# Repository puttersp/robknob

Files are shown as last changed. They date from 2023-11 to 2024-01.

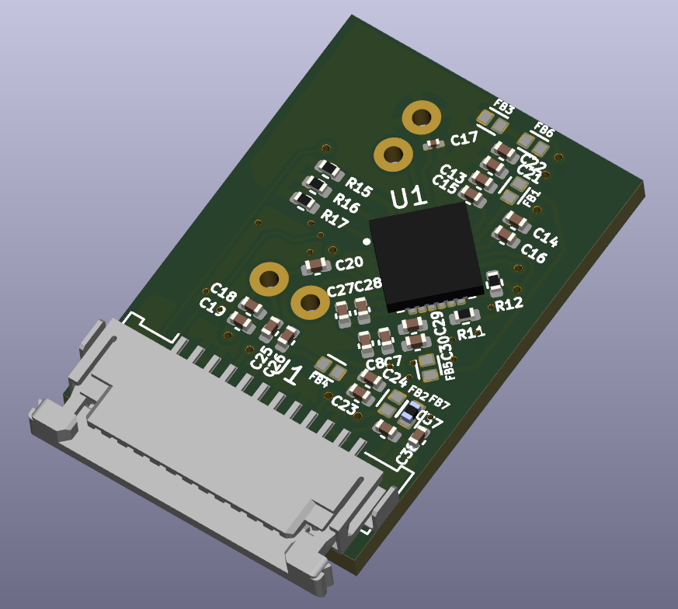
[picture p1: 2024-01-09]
electronics/lidar_pcb.png

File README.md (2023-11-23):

# robknob
## Robknob is a smartknob for robotics.
### FEATURES
- Smartknob with Haptic feedback
    - 3 Hapfic feedback modes
        - Fine steps with low detents
        - Rough steps with medium detents
        - Fine steps with medium detents and Bounded with high detents
    - Press for mode change
        - 3 steps press with strain gauges
            - Different colors displayed by LED Strips for different steps
        - LiDAR Mode for Robot Navigation
        - PID Tuning Mode
        - IMU Display
    - 240x240 Round LCD Display
- LiDAR with 4000Hz Sampling Rate 5M Range
- 6-DOF IMU for Robot Navigation
- ROS2 Compatible

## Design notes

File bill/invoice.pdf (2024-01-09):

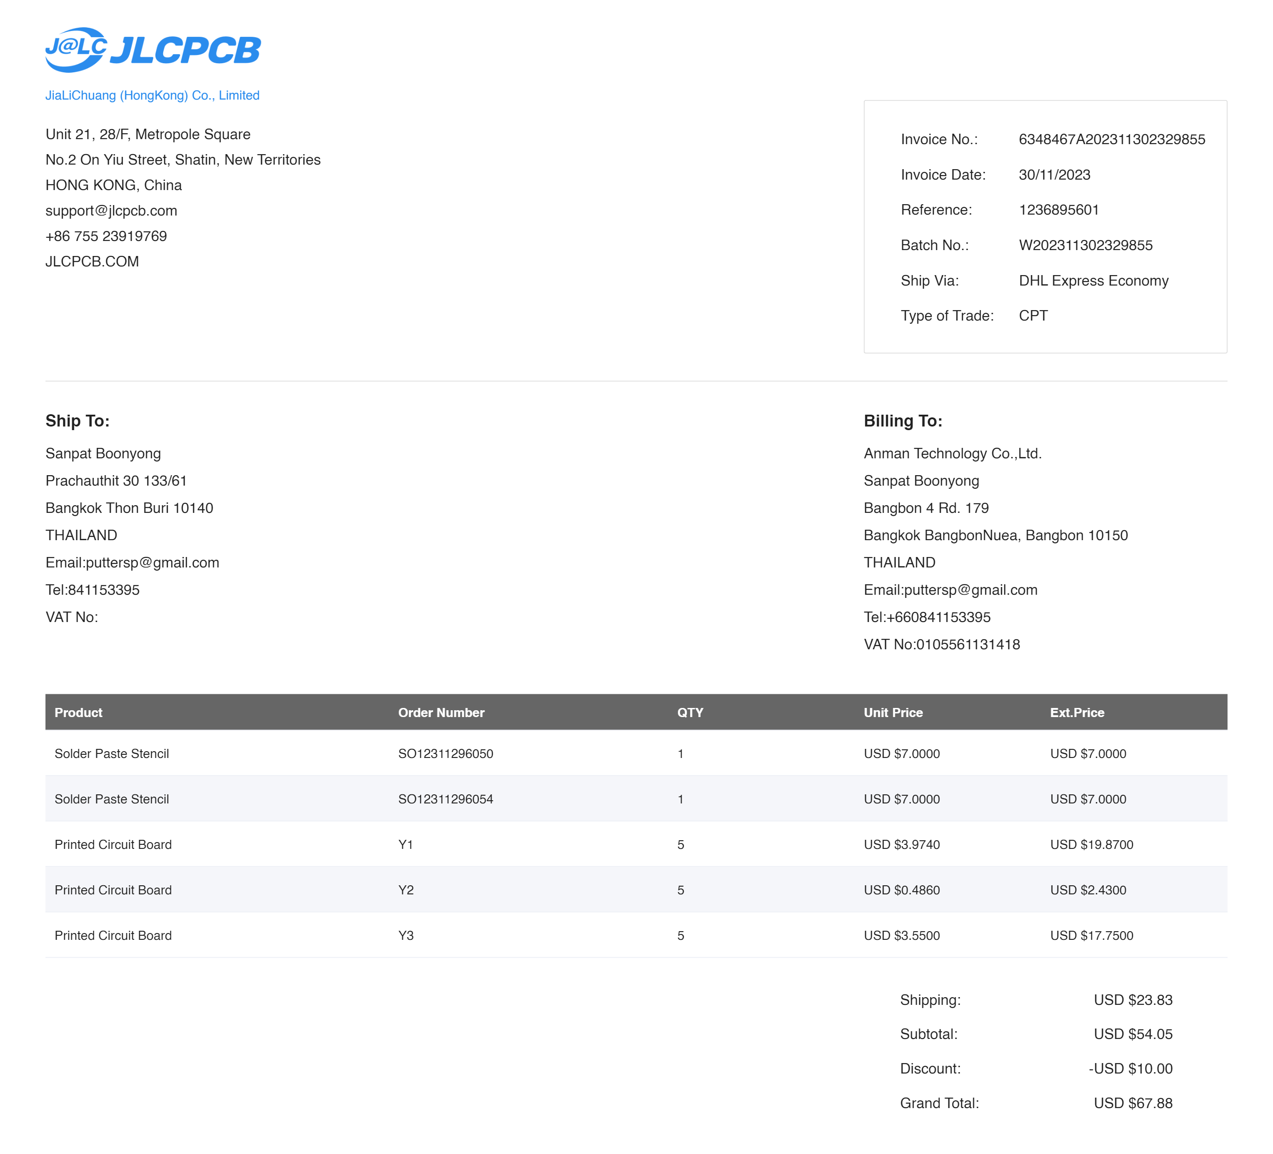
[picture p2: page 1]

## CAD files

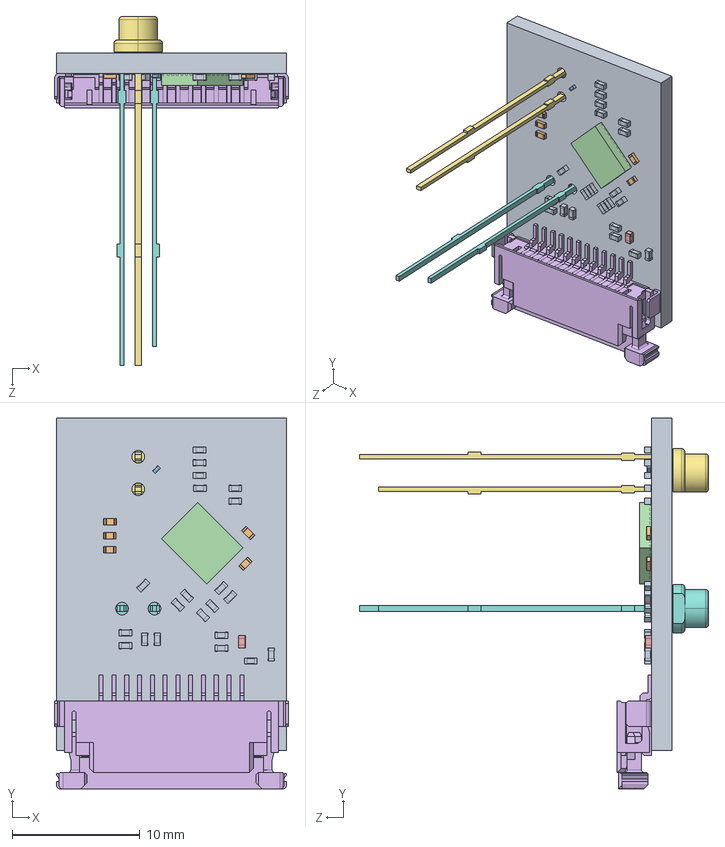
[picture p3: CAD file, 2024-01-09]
cad/Lidar.SLDASM
18.3 x 29.0 x 27.3 mm
SOLID.step x 21
SOLID-0.step x 5
SOLID-1.step
COMPOUND.step
COMPOUND-2.step
COMPOUND-3.step
COMPOUND-4.step
COMPOUND-5.step
lidar PCB.step

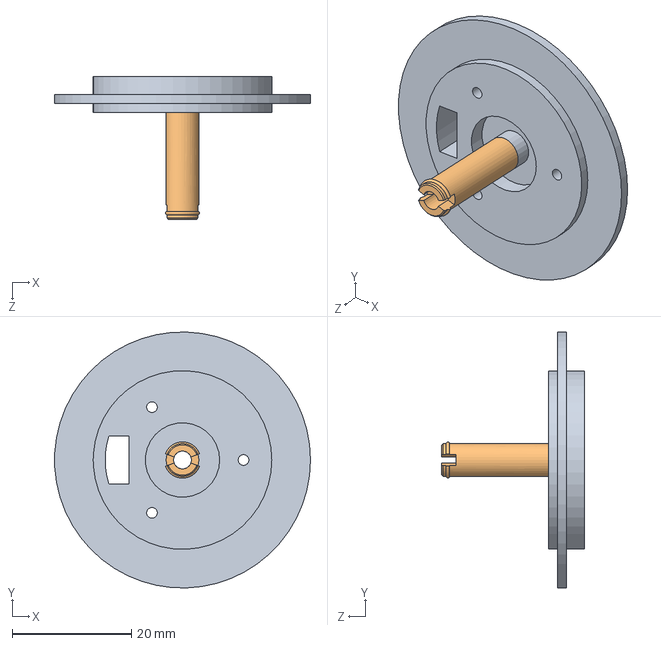
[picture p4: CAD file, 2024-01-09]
cad/MountBaseNew.SLDASM
43.0 x 43.0 x 24.0 mm
MountBaseBasePart
MountBaseLongPart

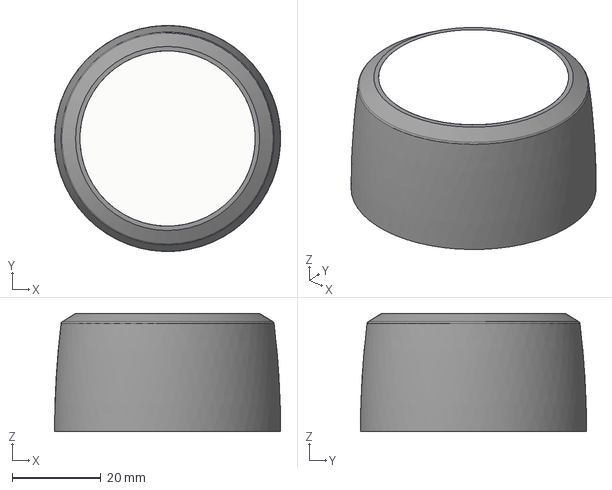
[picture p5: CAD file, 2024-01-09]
cad/KnobAssembly.step
51.0 x 51.0 x 26.7 mm

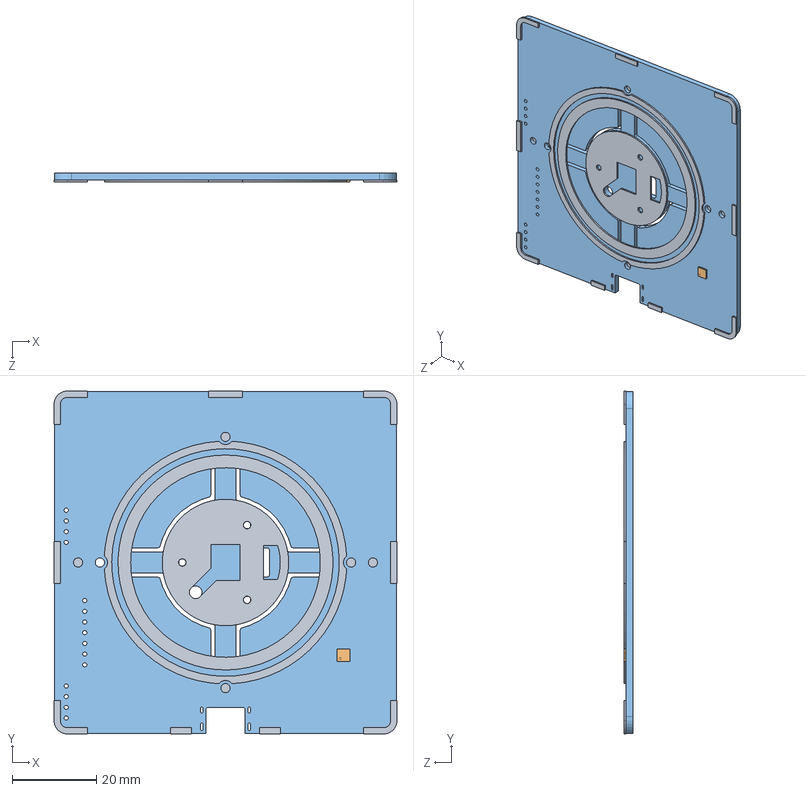
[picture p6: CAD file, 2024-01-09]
cad/Base_bare.SLDASM
81.4 x 81.4 x 2.22 mm
COMPOUND-3.step
SOLID-5.step
view_base PCB.step

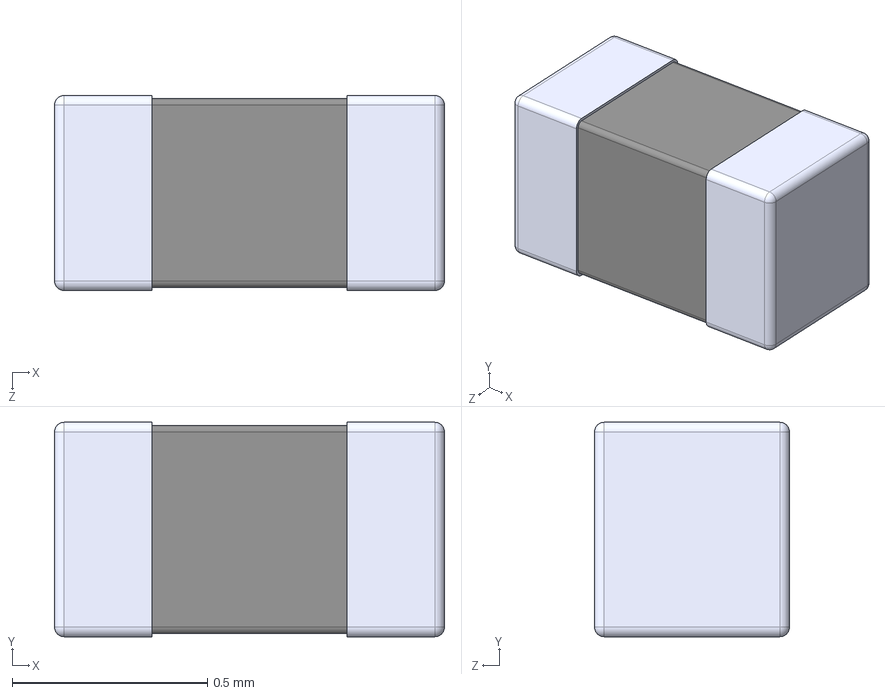
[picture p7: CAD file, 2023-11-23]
Kicad/BEADC1005X50N/NFZ15SR262SN10D.STEP
1.00 x 0.55 x 0.5 mm

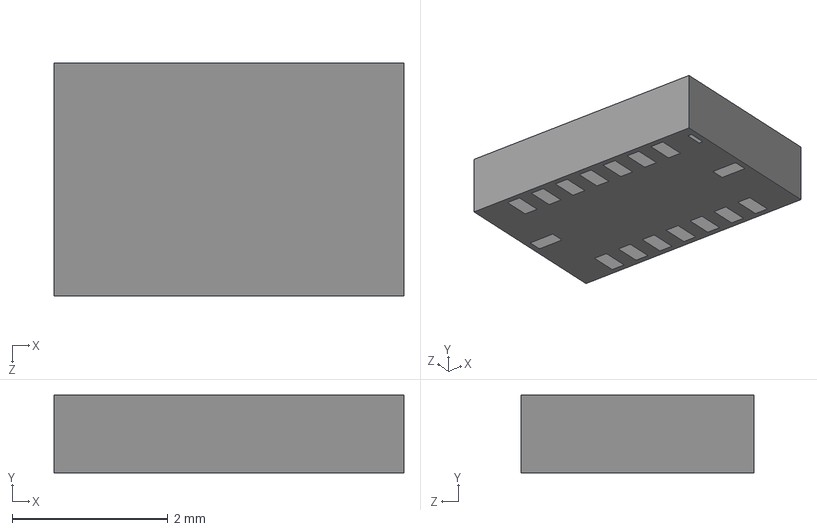
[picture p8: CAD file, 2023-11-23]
Kicad/BMI088/BMI088.step
4.50 x 1.00 x 3.00 mm

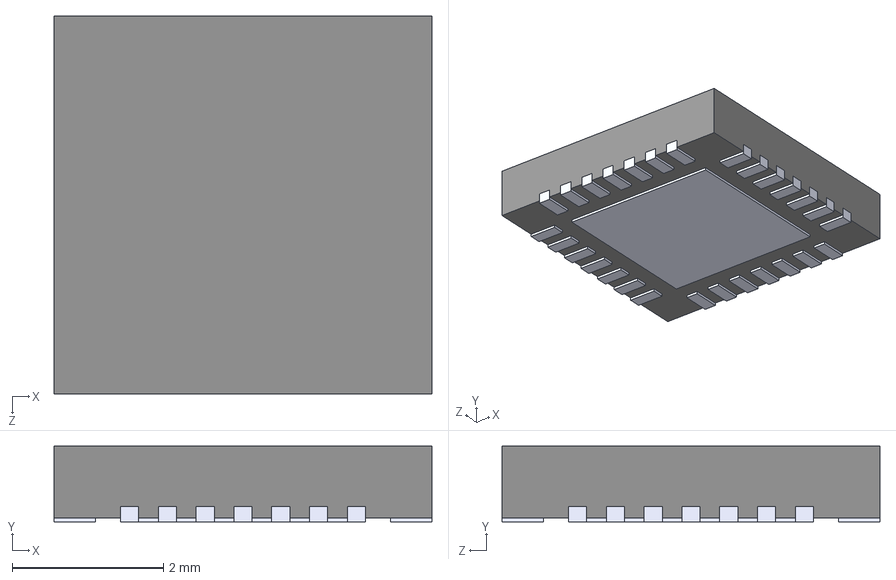
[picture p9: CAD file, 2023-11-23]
Kicad/OPT3101RHFR/CC2520RHDRG4.STEP
5.00 x 1 x 5.00 mm

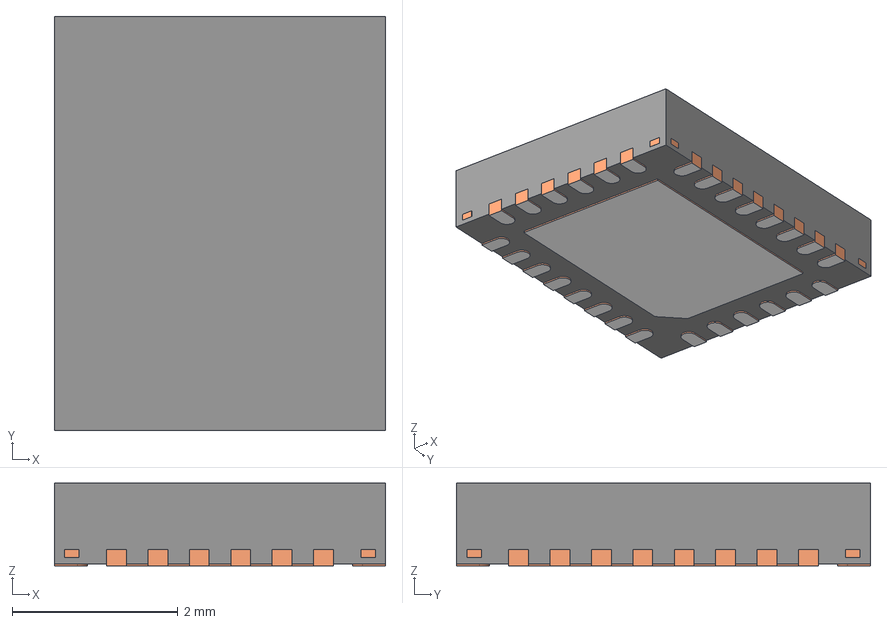
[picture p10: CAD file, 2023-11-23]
Kicad/OPT3101RHFR/OPT3101RHFR/3D/OPT3101RHFR.stp
4.00 x 5.00 x 1.00 mm
BODY-QFN
FRAME-RHF0028A
PIN1-ID

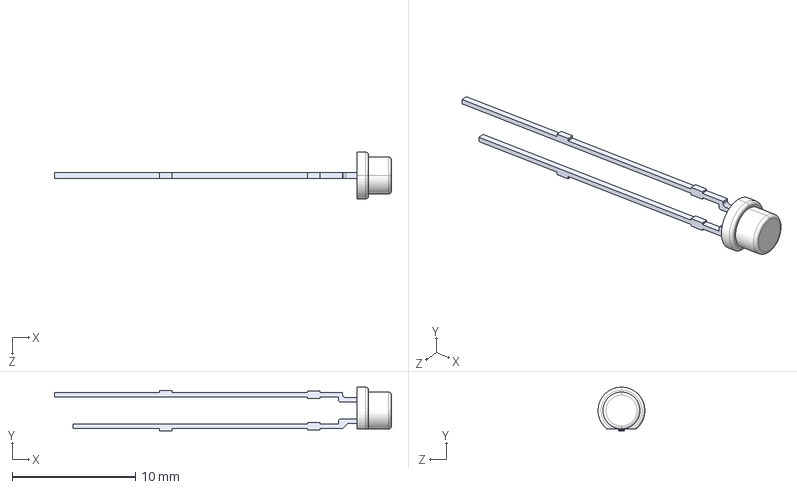
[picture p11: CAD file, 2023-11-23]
Kicad/SFH213FA/SFH_213_FA.step
27.3 x 3.55 x 3.80 mm

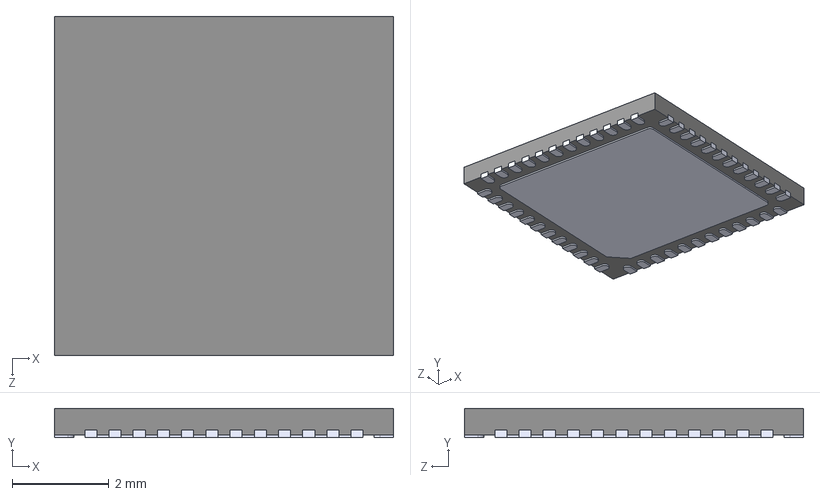
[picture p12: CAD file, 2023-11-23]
Kicad/STM32F411CEU6/STM32F411CEU6.step
7.00 x 0.6 x 7.00 mm

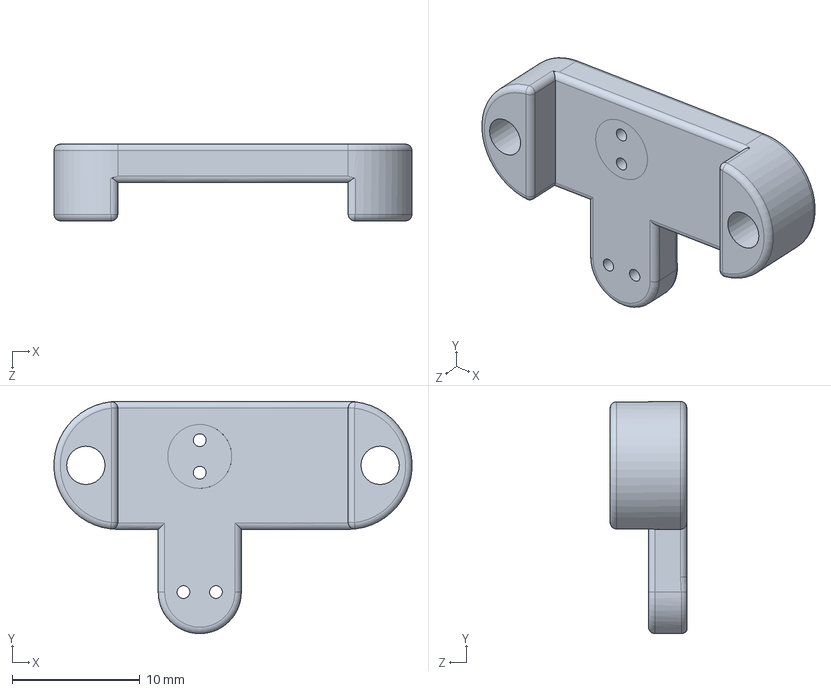
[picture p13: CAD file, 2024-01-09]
cad/lidar_mount2.SLDPRT
28.0 x 18.1 x 6.00 mm

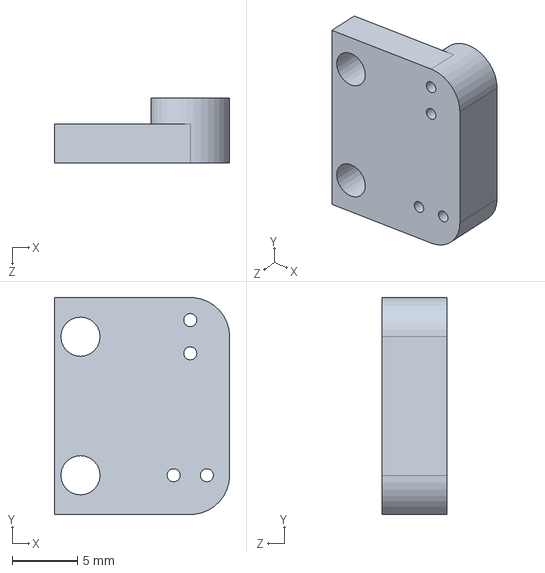
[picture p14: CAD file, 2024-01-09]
cad/lidar_mount3.SLDPRT
13.4 x 16.6 x 5.00 mm

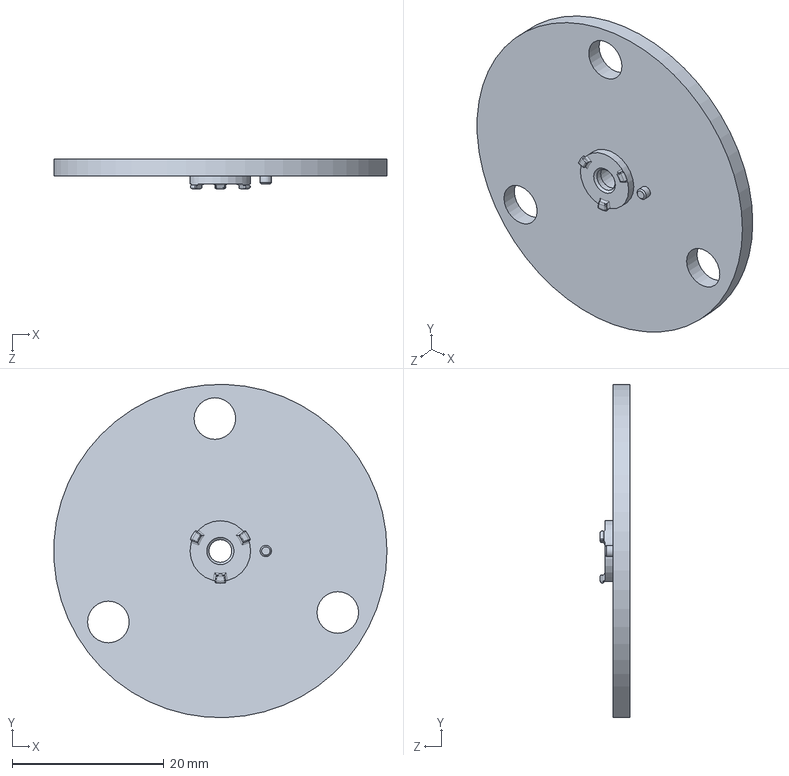
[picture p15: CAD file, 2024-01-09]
cad/ScreenPlatformNew.SLDPRT
44.0 x 44.0 x 3.90 mm

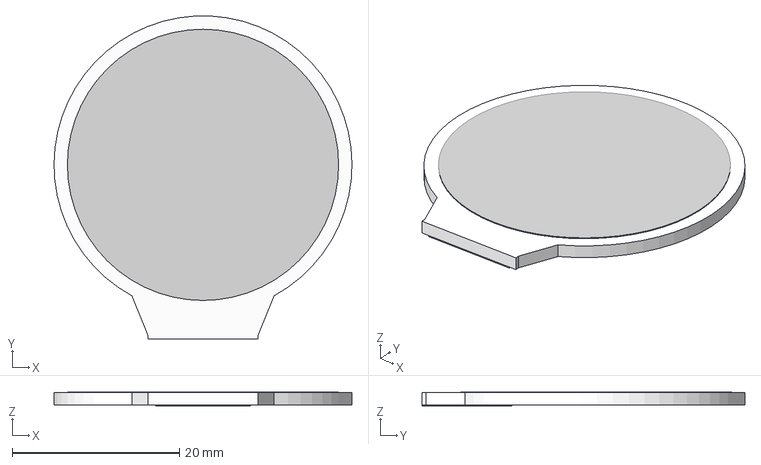
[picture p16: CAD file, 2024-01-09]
cad/TFT-Round-1.28 v1.step
35.6 x 38.6 x 1.73 mm

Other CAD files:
cad/view_base2.step
cad/Base.SLDPRT
cad/nutm5.SLDPRT
Kicad/OPT3101RHFR/OPT3101RHFR/Allegro/qfn50p400x500x100-29n-d.psm
Kicad/OPT3101RHFR/OPT3101RHFR/DEHDL/opt3101rhfr/chips/chips.prt
Kicad/fpcconncad/52207-1260.stp
cad/BLDCMotor.step
cad/BackPlate.step
cad/Enclosure.step
cad/Glass.step
cad/Lidar.SLDPRT
cad/LidarMount.SLDPRT
cad/MountBase.step
cad/MountBaseBasePart.SLDPRT
cad/MountBaseLongPart.SLDPRT
cad/MountBaseNew.SLDPRT
cad/RotorSpacer.step
cad/RotorSpacerNew.SLDPRT
cad/ScreenPCB.step
cad/ScreenPlatform.step
cad/SlipRingPlatform.SLDPRT
cad/conn_stat2.SLDPRT
cad/knob.SLDPRT
cad/lidar_mount.SLDPRT
cad/m5.SLDPRT
cad/slip ring.SLDPRT
cad/slipring_src022a12.SLDPRT

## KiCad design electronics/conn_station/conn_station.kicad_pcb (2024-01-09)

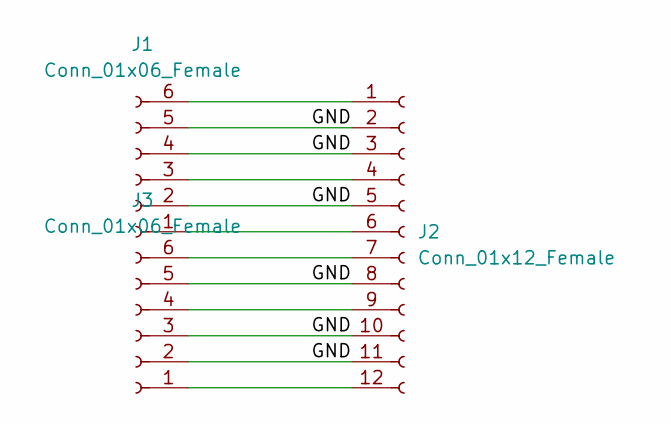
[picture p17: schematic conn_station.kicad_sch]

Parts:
J1, J3: Conn_01x06_Female; PinSocket_1x06_P2.54mm_Horizontal
J2: Conn_01x12_Female; Molex_200528-0120_1x12-1MP_P1.00mm_Horizontal

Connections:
/GND: J1.2, J1.4, J1.5, J2.2, J2.3, J2.5, J2.8, J2.10, J2.11, J2.MP, J3.2, J3.3, J3.5
unnamed: J1.1, J2.6
unnamed: J1.3, J2.4
unnamed: J1.6, J2.1
unnamed: J2.7, J3.6
unnamed: J2.9, J3.4
unnamed: J2.12, J3.1

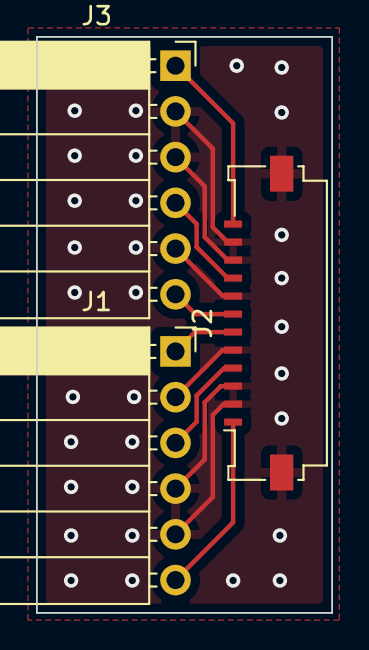
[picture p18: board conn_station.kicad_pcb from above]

Board: 2 copper layers, 16.4 x 32.0 mm, 3 parts (0 on the bottom side), 7 nets.

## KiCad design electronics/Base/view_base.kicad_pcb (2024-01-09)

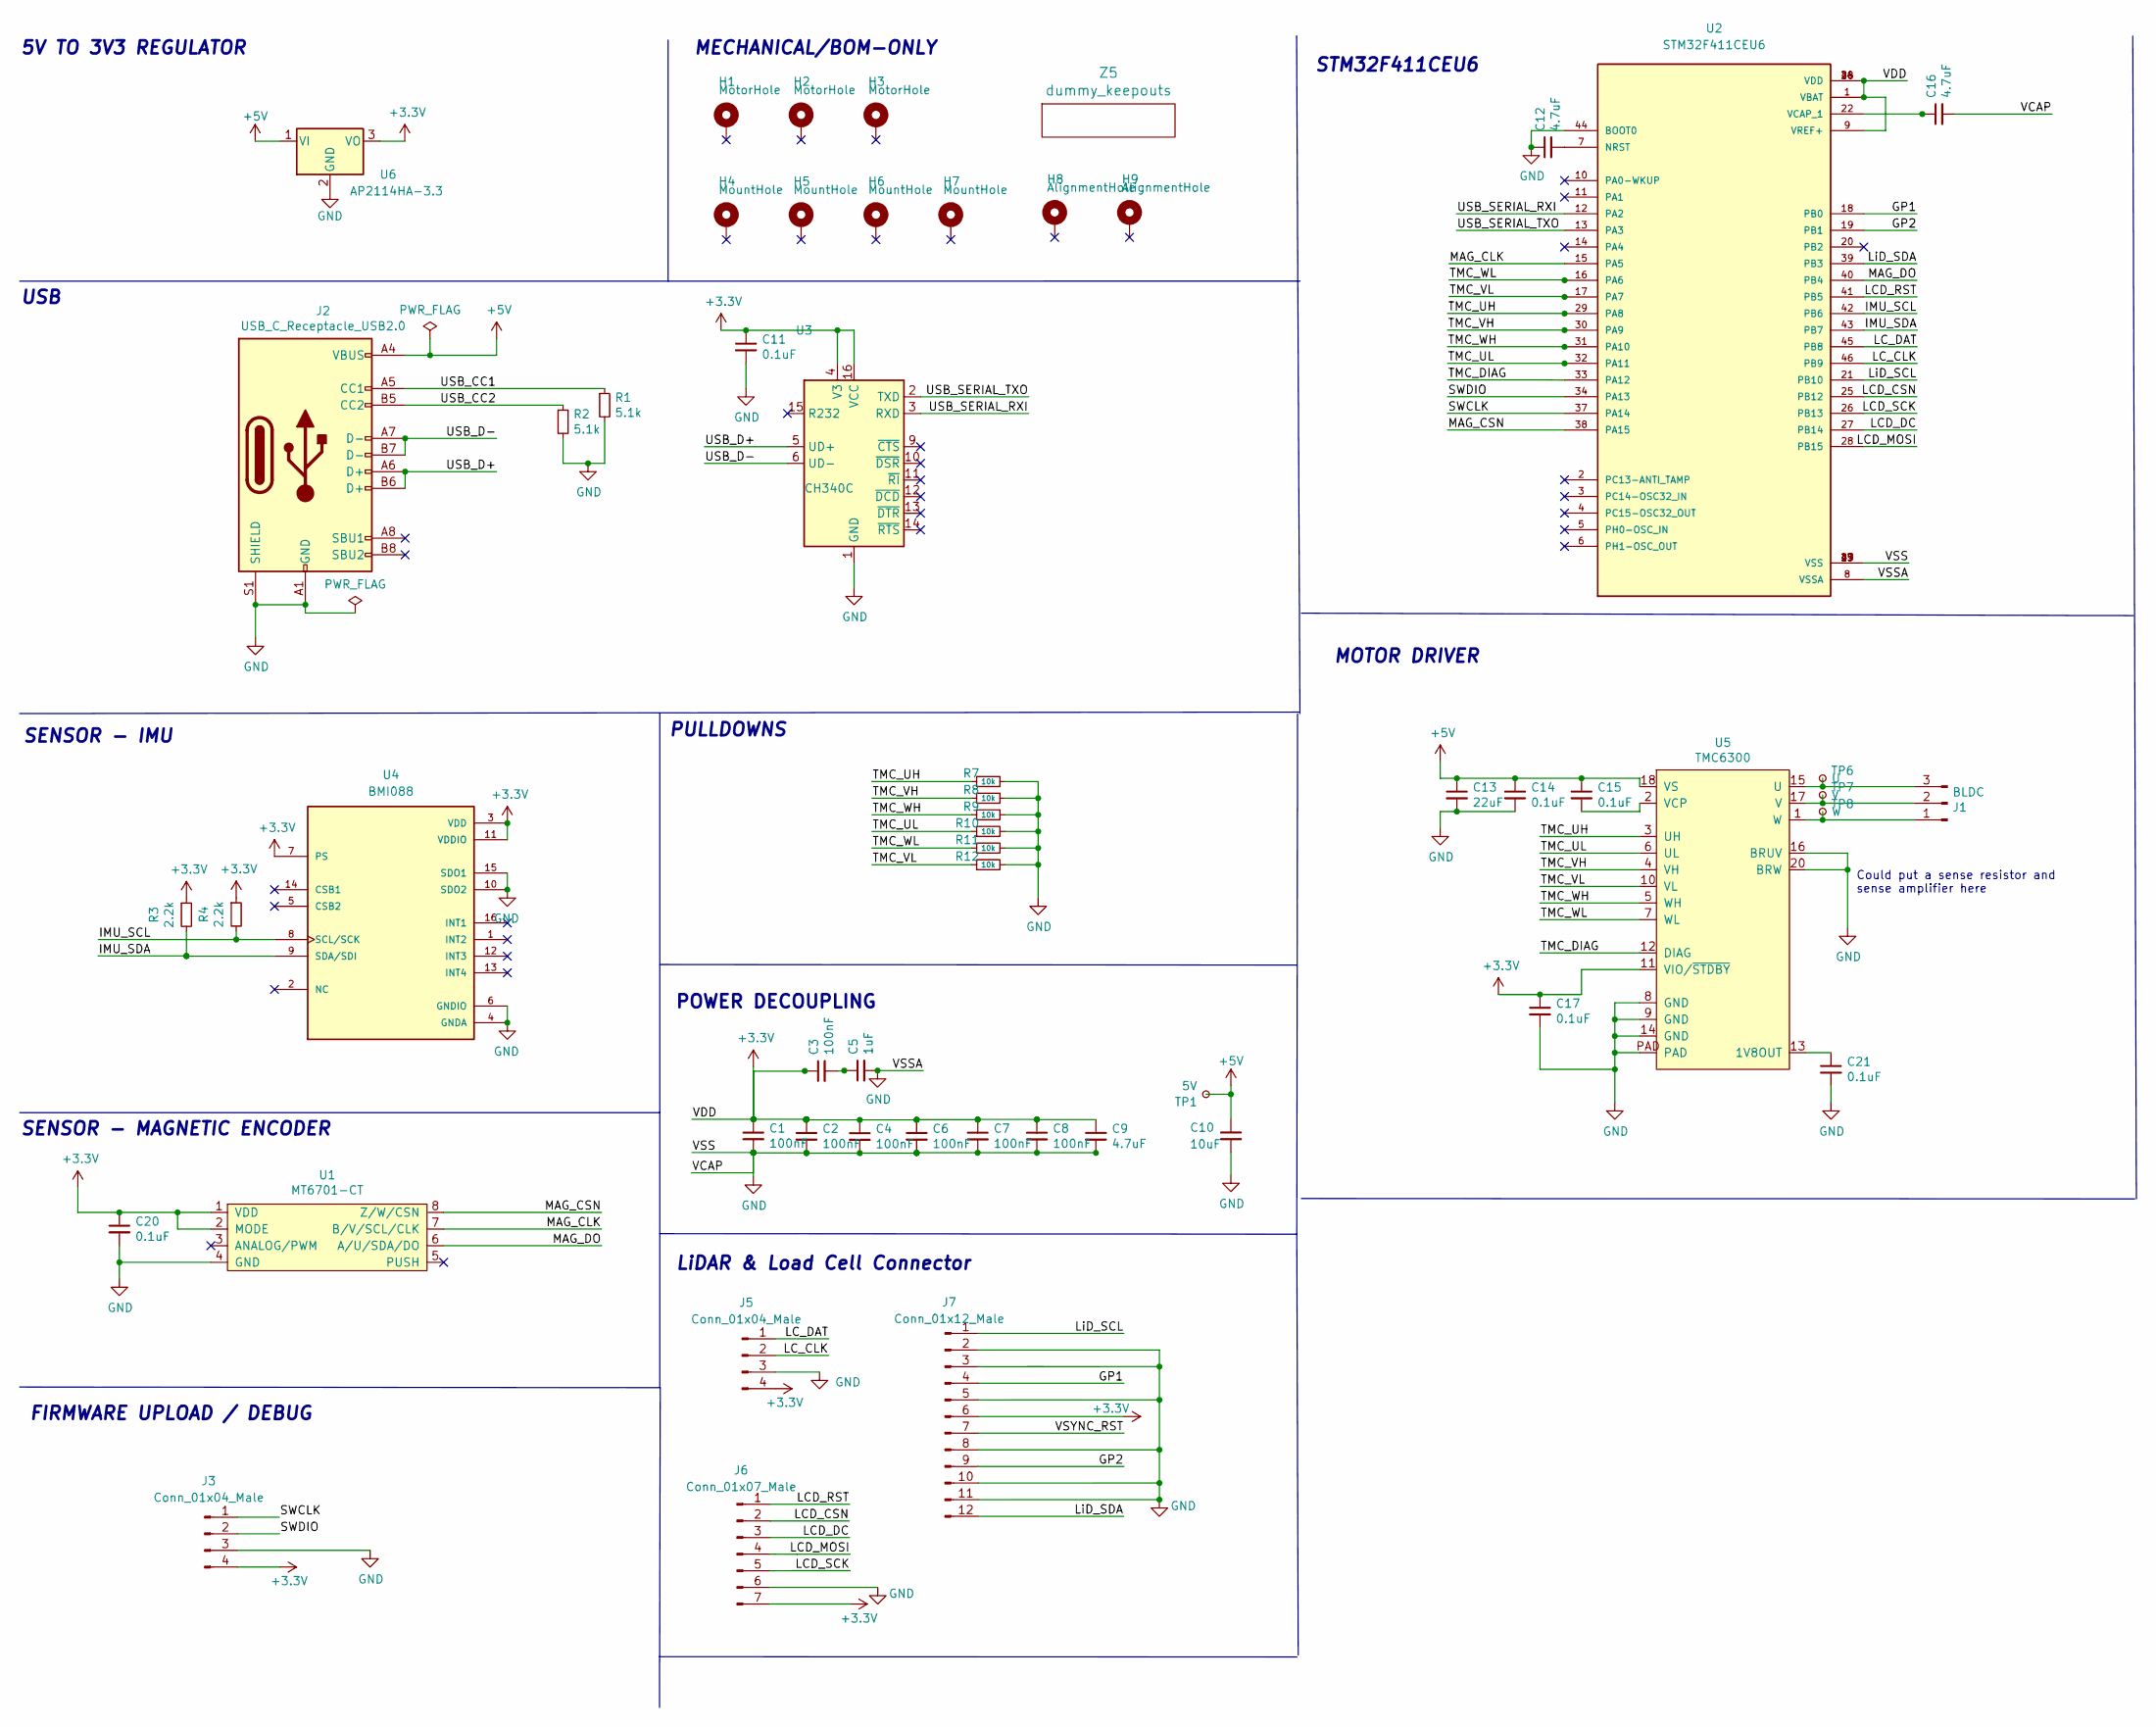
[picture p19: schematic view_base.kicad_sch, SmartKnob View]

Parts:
C1, C2, C3, C4, C6, C7, C8: 100nF; C_0603_1608Metric; LCSC C1591
C5: 1uF; C_0603_1608Metric; LCSC C1591
C9, C12, C16: 4.7uF; C_0603_1608Metric; LCSC C1591
C10: 10uF; C_0805_2012Metric; LCSC C2922480
C11, C14, C15, C17, C20, C21: 0.1uF; C_0603_1608Metric; LCSC C1591
C13: 22uF; C_0805_2012Metric; LCSC C98190
H1, H2, H3: MotorHole; MountingHole_M1.6; LCSC C2931389
H4, H5, H6, H7: MountHole; MountingHole_2.2mm_M2_ISO7380_Pad_NonVirtual; LCSC C2911210 or C2911532 (screw), C2961595 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
H8, H9: AlignmentHole; MountingHole_2.2mm_M2_ISO7380_Pad_NonVirtual
J1: BLDC; 532610371; LCSC C293630
J2: USB_C_Receptacle_USB2.0; USB4510_NoPaste; LCSC C428463
J3, J5: Conn_01x04_Male; PinHeader_1x04_P2.54mm_Vertical
J6: Conn_01x07_Male; PinHeader_1x07_P2.54mm_Vertical
J7: Conn_01x12_Male; Molex_200528-0120_1x12-1MP_P1.00mm_Horizontal
R1, R2: 5.1k; R_0603_1608Metric; LCSC C105580
R3, R4: 2.2k; R_0603_1608Metric; LCSC C4190
R7, R8, R9, R10, R11, R12: 10k; R_0603_1608Metric; LCSC C98220
TP1: 5V; TestPoint_Pad_D2.0mm_ValueSilk
TP6: U; TestPoint_Pad_D2.0mm_ValueSilk
TP7: V; TestPoint_Pad_D2.0mm_ValueSilk
TP8: W; TestPoint_Pad_D2.0mm_ValueSilk
U1: MT6701-CT; SOIC-8_3.9x4.9mm_P1.27mm; LCSC C2856764, or C3003196
U2: STM32F411CEU6; QFN50P700X700X60-49N; PARTREV 7
U3: CH340C; SOIC-16_3.9x9.9mm_P1.27mm; LCSC C84681
U4: BMI088; PQFN50P450X300X100-16N
U5: TMC6300; QFN-20-1EP_3x3mm_P0.4mm_EP1.65x1.65mm_ThermalVias_LargerVia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; Digikey TMC6300-LA-T
U6: AP2114HA-3.3; SOT-223-3_TabPin2_InGndOut; LCSC C460314
Z5: dummy_keepouts; ViewKeepouts3d

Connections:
+3V3: C1.1, C2.1, C3.1, C4.1, C6.1, C7.1, C8.1, C9.1, C11.1, C17.1, C20.1, J3.4, J5.4, J6.7, J7.6, R3.1, R4.1, U1.1 (VDD), U1.2 (MODE), U2.1 (VBAT), U2.9 (VREF+), U2.24 (VDD), U2.36 (VDD), U2.48 (VDD), U3.4 (V3), U3.16 (VCC), U4.3 (VDD), U4.7 (PS), U4.11 (VDDIO), U5.11 (VIO/~STDBY), U6.3 (VO)
+5V: C10.1, C13.1, C14.1, C15.1, J2.A4 (VBUS), J2.A9 (VBUS), J2.B4 (VBUS), J2.B9 (VBUS), TP1.1, U5.18 (VS), U6.1 (VI)
/GP1: J7.4, U2.18 (PB0)
/GP2: J7.9, U2.19 (PB1)
/IMU_SCL: R4.2, U2.42 (PB6), U4.8 (SCL/SCK)
/IMU_SDA: R3.2, U2.43 (PB7), U4.9 (SDA/SDI)
/LCD_CSN: J6.2, U2.25 (PB12)
/LCD_DC: J6.3, U2.27 (PB14)
/LCD_MOSI: J6.4, U2.28 (PB15)
/LCD_RST: J6.1, U2.41 (PB5)
/LCD_SCK: J6.5, U2.26 (PB13)
/LC_CLK: J5.2, U2.46 (PB9)
/LC_DAT: J5.1, U2.45 (PB8)
/LiD_SCL: J7.1, U2.21 (PB10)
/LiD_SDA: J7.12, U2.39 (PB3)
/MAG_CLK: U1.7 (B/V/SCL/CLK), U2.15 (PA5)
/MAG_CSN: U1.8 (Z/W/CSN), U2.38 (PA15)
/MAG_DO: U1.6 (A/U/SDA/DO), U2.40 (PB4)
/SWCLK: J3.1, U2.37 (PA14)
/SWDIO: J3.2, U2.34 (PA13)
/TMC_DIAG: U2.33 (PA12), U5.12 (DIAG)
/TMC_UH: R7.1, U2.29 (PA8), U5.3 (UH)
/TMC_UL: R10.1, U2.32 (PA11), U5.6 (UL)
/TMC_VH: R8.1, U2.30 (PA9), U5.4 (VH)
/TMC_VL: R12.1, U2.17 (PA7), U5.10 (VL)
/TMC_WH: R9.1, U2.31 (PA10), U5.5 (WH)
/TMC_WL: R11.1, U2.16 (PA6), U5.7 (WL)
/USB_CC1: J2.A5 (CC1), R1.1
/USB_CC2: J2.B5 (CC2), R2.1
/USB_D+: J2.A6 (D+), J2.B6 (D+), U3.5 (UD+)
/USB_D-: J2.A7 (D-), J2.B7 (D-), U3.6 (UD-)
/USB_SERIAL_RXI: U2.12 (PA2), U3.3 (RXD)
/USB_SERIAL_TXO: U2.13 (PA3), U3.2 (TXD)
/VSYNC_RST: J7.7
GND: C1.2, C2.2, C4.2, C5.2, C6.2, C7.2, C8.2, C9.2, C10.2, C11.2, C12.1, C13.2, C14.2, C16.2, C17.2, C20.2, C21.2, J2.A1 (GND), J2.A12 (GND), J2.B1 (GND), J2.B12 (GND), J2.S1 (SHIELD), J3.3, J5.3, J6.6, J7.2, J7.3, J7.5, J7.8, J7.10, J7.11, J7.MP, R1.2, R2.2, R7.2, R8.2, R9.2, R10.2, R11.2, R12.2, U1.4 (GND), U2.8 (VSSA), U2.23 (VSS), U2.35 (VSS), U2.44 (BOOT0), U2.47 (VSS), U2.49 (VSS), U3.1 (GND), U4.4 (GNDA), U4.6 (GNDIO), U4.10 (SDO2), U4.15 (SDO1), U5.8 (GND), U5.9 (GND), U5.14 (GND), U5.16 (BRUV), U5.20 (BRW), U5.PAD, U6.2 (GND)
unnamed: C3.2, C5.1
unnamed: C12.2, U2.7 (NRST)
unnamed: C15.2, U5.2 (VCP)
unnamed: C16.1, U2.22 (VCAP_1)
unnamed: C21.1, U5.13 (1V8OUT)
unnamed: J1.1, TP8.1, U5.1 (W)
unnamed: J1.2, TP7.1, U5.17 (V)
unnamed: J1.3, TP6.1, U5.15 (U)

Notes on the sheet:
5V TO 3V3 REGULATOR
Could put a sense resistor and sense amplifier here
STM32F411CEU6
SENSOR - MAGNETIC ENCODER
MOTOR DRIVER
MECHANICAL/BOM-ONLY
POWER DECOUPLING
LiDAR & Load Cell Connector
USB
SENSOR - IMU
PULLDOWNS
FIRMWARE UPLOAD / DEBUG

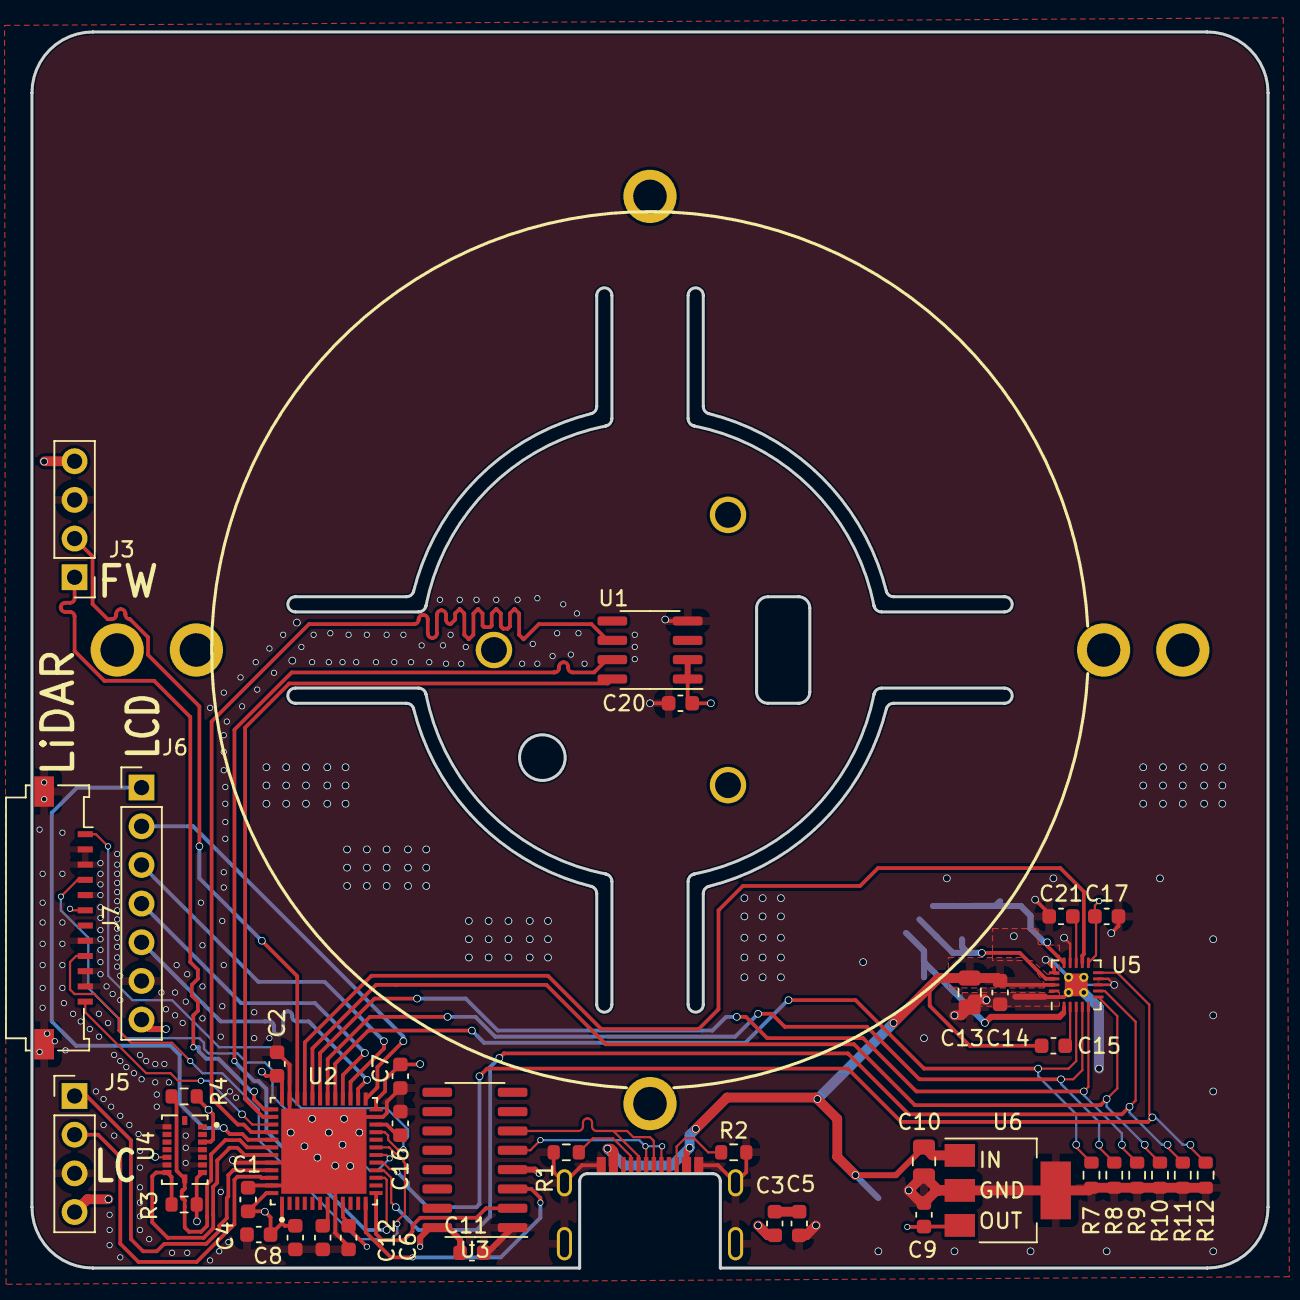
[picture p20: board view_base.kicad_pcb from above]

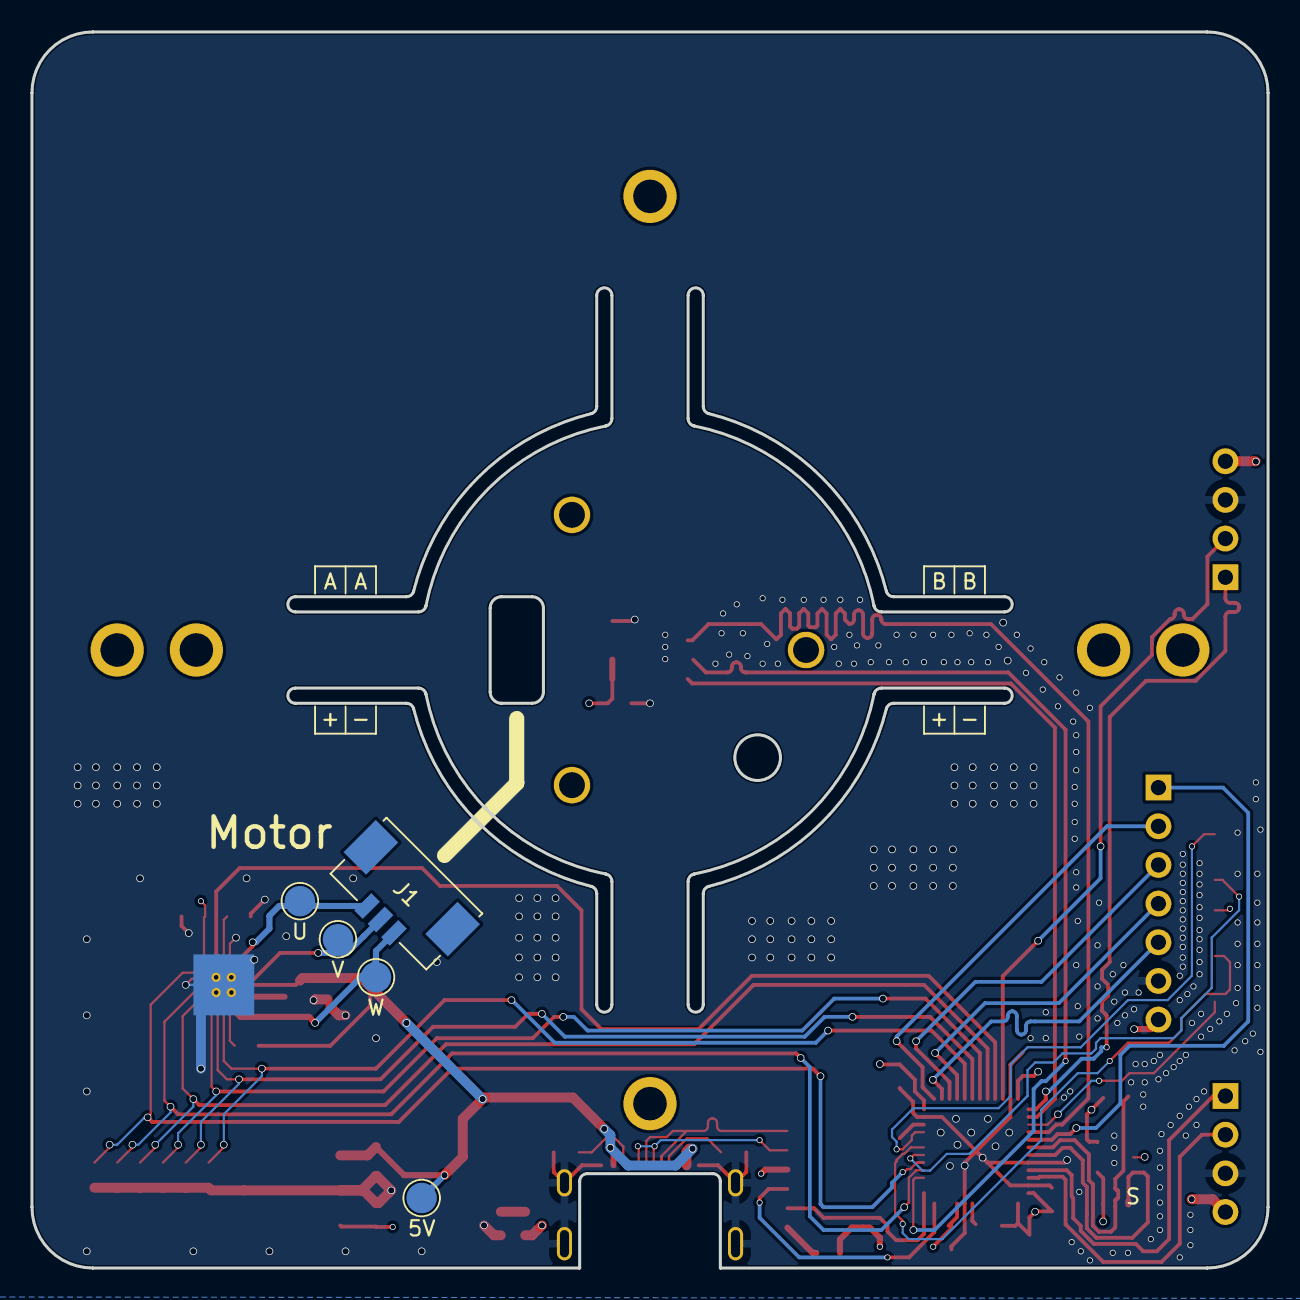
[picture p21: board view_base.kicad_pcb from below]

Board: 4 copper layers, 81.2 x 81.2 mm, 55 parts (5 on the bottom side), 42 nets.

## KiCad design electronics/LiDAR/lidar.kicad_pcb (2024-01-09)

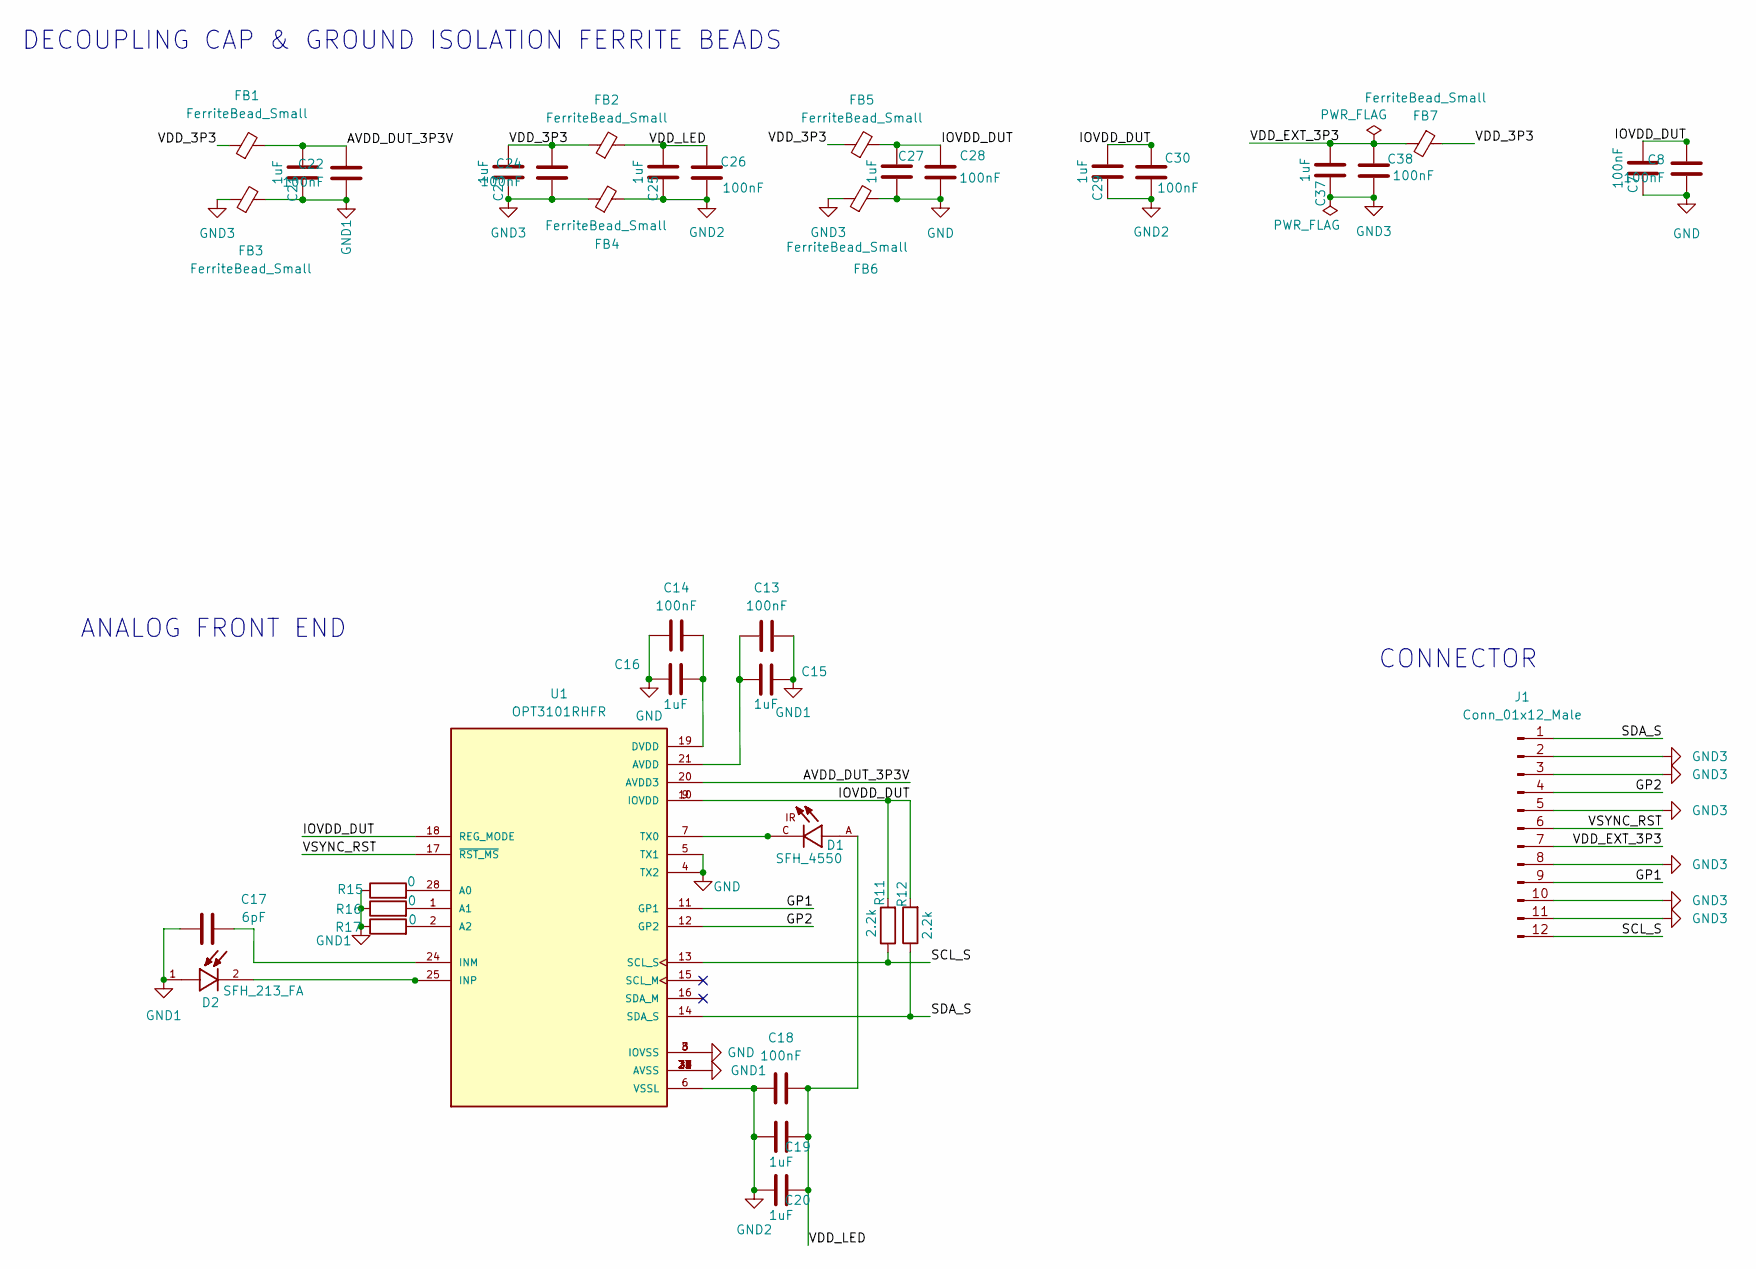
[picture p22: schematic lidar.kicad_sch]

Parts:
C7, C8, C13, C14, C18, C22, C24, C26, C28, C30, C38: 100nF; C_0402_1005Metric
C15, C16, C19, C20, C21, C23, C25, C27, C29, C37: 1uF; C_0402_1005Metric
C17: 6pF; C_0201_0603Metric
D1: SFH_4550; DIO_SFH_4550; PARTREV 1.6
D2: SFH_213_FA; XDCR_SFH_213_FA; PARTREV 1.3
FB1, FB2, FB3, FB4, FB5, FB6, FB7: FerriteBead_Small; BEADC1005X50N
J1: Conn_01x12_Male; Molex_200528-0120_1x12-1MP_P1.00mm_Horizontal
R11, R12: 2.2k; R_0402_1005Metric
R15, R16, R17: 0; R_0402_1005Metric
U1: OPT3101RHFR; IC_OPT3101RHFR; PARTREV A

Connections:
/AVDD_DUT_3P3V: C21.1, C22.2, FB1.2, U1.20 (AVDD3)
/GP1: J1.9, U1.11 (GP1)
/GP2: J1.4, U1.12 (GP2)
/IOVDD_DUT: C7.1, C8.2, C27.1, C28.2, C29.1, C30.2, FB5.2, R11.2, R12.2, U1.9 (IOVDD), U1.10 (IOVDD), U1.18 (REG_MODE)
/SCL_S: J1.12, R11.1, U1.13 (SCL_S)
/SDA_S: J1.1, R12.1, U1.14 (SDA_S)
/VDD_3P3: C23.1, C24.2, FB1.1, FB2.1, FB5.1, FB7.1
/VDD_EXT_3P3: C37.1, C38.2, FB7.2, J1.7
/VDD_LED: C18.1, C19.2, C20.2, C25.1, C26.2, D1.A, FB2.2
/VSYNC_RST: J1.6, U1.17 (~RST_MS)
GND: C7.2, C8.1, C14.2, C16.1, C27.2, C28.1, FB6.2, U1.3 (IOVSS), U1.4 (TX2), U1.5 (TX1), U1.8 (IOVSS)
GND1: C13.1, C15.2, C17.1, C21.2, C22.1, D2.1, FB3.2, R15.1, R16.1, R17.1, U1.23 (AVSS), U1.26 (AVSS), U1.27 (AVSS), U1.29 (AVSS), U1.30 (AVSS), U1.31 (AVSS), U1.32 (AVSS), U1.33 (AVSS), U1.34 (AVSS)
GND2: C18.2, C19.1, C20.1, C25.2, C26.1, C29.2, C30.1, FB4.2, U1.6 (VSSL)
GND3: C23.2, C24.1, C37.2, C38.1, FB3.1, FB4.1, FB6.1, J1.2, J1.3, J1.5, J1.8, J1.10, J1.11
unnamed: C13.2, C15.1, U1.21 (AVDD)
unnamed: C14.1, C16.2, U1.19 (DVDD)
unnamed: C17.2, U1.24 (INM)
unnamed: D1.C, U1.7 (TX0)
unnamed: D2.2, U1.25 (INP)
unnamed: R15.2, U1.28 (A0)
unnamed: R16.2, U1.1 (A1)
unnamed: R17.2, U1.2 (A2)

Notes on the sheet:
ANALOG FRONT END
DECOUPLING CAP & GROUND ISOLATION FERRITE BEADS
CONNECTOR

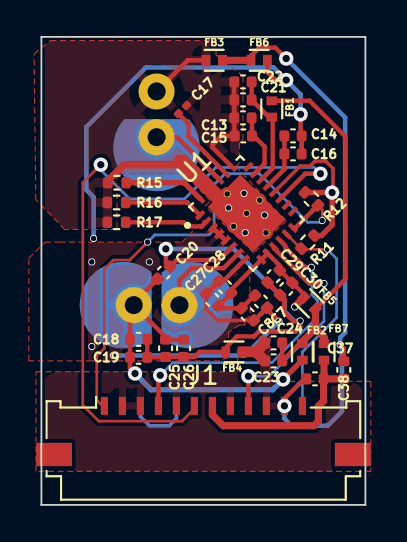
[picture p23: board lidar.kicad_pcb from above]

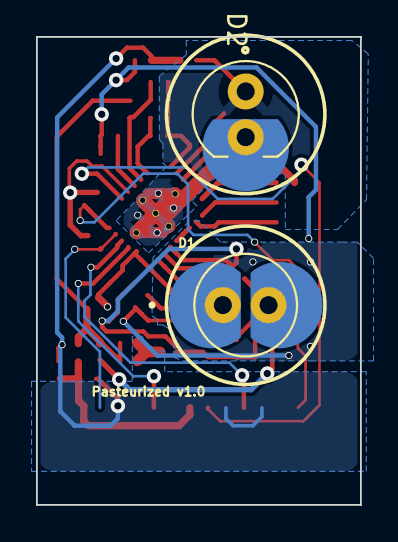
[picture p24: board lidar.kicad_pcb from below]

Board: 4 copper layers, 18.0 x 26.0 mm, 38 parts (2 on the bottom side), 22 nets.

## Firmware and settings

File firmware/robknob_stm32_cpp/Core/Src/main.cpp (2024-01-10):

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
/* Includes ------------------------------------------------------------------*/
#include "main.h"
#include "SimpleFOC_stm32.h"

I2C_HandleTypeDef hi2c1;
I2C_HandleTypeDef hi2c2;

SPI_HandleTypeDef hspi1;

TIM_HandleTypeDef htim1;
TIM_HandleTypeDef htim2;
TIM_HandleTypeDef htim3;

UART_HandleTypeDef huart2;

/* USER CODE BEGIN PV */
uint8_t acc[6];
uint8_t gyro[6];
/* USER CODE END PV */

void SystemClock_Config(void);
static void MX_GPIO_Init(void);
static void MX_I2C1_Init(void);
static void MX_I2C2_Init(void);
static void MX_SPI1_Init(void);
static void MX_TIM1_Init(void);
static void MX_TIM2_Init(void);
static void MX_TIM3_Init(void);
static void MX_USART2_UART_Init(void);
/**
  * @brief  The application entry point.
  * @retval int
  */
int main(void)
{
  /* MCU Configuration--------------------------------------------------------*/

  /* Reset of all peripherals, Initializes the Flash interface and the Systick. */
  HAL_Init();

  /* Configure the system clock */
  SystemClock_Config();

  /* Initialize all configured peripherals */
  MX_GPIO_Init();
  MX_I2C1_Init();
  MX_I2C2_Init();
  MX_SPI1_Init();
  MX_TIM1_Init();
  MX_TIM2_Init();
  MX_TIM3_Init();
  MX_USART2_UART_Init();
  /* Infinite loop */
  /* USER CODE BEGIN WHILE */
  while (1)
  {
    /* USER CODE END WHILE */

    /* USER CODE BEGIN 3 */
  }
  /* USER CODE END 3 */
}

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
/* USER CODE BEGIN 4 */
void acc_write(uint8_t* cmd){
	HAL_I2C_Master_Transmit(&hi2c1, 0x18 << 1, cmd, sizeof(cmd),HAL_MAX_DELAY);
}

void acc_read(){
	uint8_t acc[6];
	HAL_I2C_Master_Receive(&hi2c1, 0x18 << 1, acc, 6, 1000);
}

void gyro_write(uint8_t* cmd){
	HAL_I2C_Master_Transmit(&hi2c1, 0x68 << 1, cmd, sizeof(cmd),HAL_MAX_DELAY);
}

void gyro_read(){
	uint8_t gyro[6];
	HAL_I2C_Master_Receive(&hi2c1, 0x68 << 1, gyro, 6, 1000);
}
/* USER CODE END 4 */
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


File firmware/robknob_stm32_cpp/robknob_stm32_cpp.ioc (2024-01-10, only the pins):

Mcu.UserName=STM32F411CEUx
PA0-WKUP.Signal=SYS_WKUP
PA10.Signal=S_TIM1_CH3
PA11.Signal=S_TIM1_CH4
PA12.Signal=GPIO_Input
PA13.Signal=SYS_JTMS-SWDIO
PA14.Signal=SYS_JTCK-SWCLK
PA15.Signal=GPIO_Output
PA2.Signal=USART2_TX
PA3.Signal=USART2_RX
PA5.Signal=SPI1_SCK
PA6.Signal=S_TIM3_CH1
PA7.Signal=S_TIM3_CH2
PA8.Signal=S_TIM1_CH1
PA9.Signal=S_TIM1_CH2
PB0.Signal=GPIO_Input
PB1.Signal=GPIO_Input
PB10.Signal=I2C2_SCL
PB3.Signal=I2C2_SDA
PB4.Signal=SPI1_MISO
PB5.Signal=SPI1_MOSI
PB6.Signal=I2C1_SCL
PB7.Signal=I2C1_SDA

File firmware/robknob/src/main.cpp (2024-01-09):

// Open loop motor control example
#include <SimpleFOC.h>

// BLDC motor & driver instance
// BLDCMotor motor = BLDCMotor(pole pair number, phase resistance (optional) );
BLDCMotor motor = BLDCMotor(4);
//  BLDCDriver6PWM( int phA_h, int phA_l, int phB_h, int phB_l, int phC_h, int phC_l, int en)
//  - phA_h, phA_l - A phase pwm pin high/low pair 
//  - phB_h, phB_l - B phase pwm pin high/low pair
//  - phB_h, phC_l - C phase pwm pin high/low pair
//  - enable pin    - (optional input)
BLDCDriver6PWM driver = BLDCDriver6PWM(PA8,PA11, PA9, PA7, PA10, PA6);

// instantiate the commander
Commander command = Commander(Serial);
void doTarget(char* cmd) { command.scalar(&motor.target, cmd); }

void setup() {

  // driver config
  // power supply voltage [V]
  driver.voltage_power_supply = 5;
  driver.init();
  // link the motor and the driver
  motor.linkDriver(&driver);

  // limiting motor movements
  // motor.phase_resistance = 3.52 // [Ohm]
  // motor.current_limit = 2;   // [Amps] - if phase resistance defined
  motor.voltage_limit = 5;   // [V] - if phase resistance not defined
  motor.velocity_limit = 30; // [rad/s] cca 50rpm
 
  // open loop control config
  motor.controller = MotionControlType::velocity_openloop;

  // init motor hardware
  motor.init();

  // add target command T
  command.add('T', doTarget, "target velocity");

  Serial.begin(115200);
  Serial.println("Motor ready!");
  Serial.println("Set target velocity [rad/s]");
  _delay(1000);
}
void loop() {

  // open loop velocity movement
  // using motor.voltage_limit and motor.velocity_limit
  motor.move();

  // user communication
  command.run();
}

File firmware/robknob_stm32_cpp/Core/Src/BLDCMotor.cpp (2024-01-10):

/*
 * BLDCMotor.cpp
 *
 *  Created on: Jan 10, 2024
 *      Author: putte
 */

#include "BLDCMotor.h"

 // BLDCMotor( int pp , float R)
 // - pp            - pole pair number
 // - R             - motor phase resistance
 BLDCMotor::BLDCMotor(int pp, float _R)
 : FOCMotor()
 {
   // save pole pairs number
   pole_pairs = pp;
   // save phase resistance number
   phase_resistance = _R;
   // torque control type is voltage by default
   torque_controller = TorqueControlType::voltage;
 }


 void BLDCMotor::linkDriver(BLDCDriver* _driver) {
   driver = _driver;
 }

 // init hardware pins
 void BLDCMotor::init() {
   // if no current sensing and the user has set the phase resistance of the motor use current limit to calculate the voltage limit
   if( !current_sense && _isset(phase_resistance)) {
     float new_voltage_limit = current_limit * (phase_resistance); // v_lim = current_lim / (3/2 phase resistance) - worst case
     // use it if it is less then voltage_limit set by the user
     voltage_limit = new_voltage_limit < voltage_limit ? new_voltage_limit : voltage_limit;
   }
   // sanity check for the voltage limit configuration
   if(voltage_limit > driver->voltage_limit) voltage_limit =  driver->voltage_limit;
   // constrain voltage for sensor alignment
   if(voltage_sensor_align > voltage_limit) voltage_sensor_align = voltage_limit;

   // update the controller limits
   if(current_sense){
     // current control loop controls voltage
     PID_current_q.limit = voltage_limit;
     PID_current_d.limit = voltage_limit;
     // velocity control loop controls current
     PID_velocity.limit = current_limit;
   }else{
     PID_velocity.limit = voltage_limit;
   }
   P_angle.limit = velocity_limit;

   _delay(500);
   // enable motor
   enable();
   _delay(500);
 }


 // disable motor driver
 void BLDCMotor::disable()
 {
   // set zero to PWM
   driver->setPwm(0, 0, 0);
   // disable the driver
   driver->disable();
   // motor status update
   enabled = 0;
 }
 // enable motor driver
 void BLDCMotor::enable()
 {
   // enable the driver
   driver->enable();
   // set zero to PWM
   driver->setPwm(0, 0, 0);
   // motor status update
   enabled = 1;
 }

 // FOC initialization function
 int  BLDCMotor::initFOC( float zero_electric_offset, Direction _sensor_direction) {
   int exit_flag = 1;
   // align motor if necessary
   // alignment necessary for encoders!
   if(_isset(zero_electric_offset)){
     // abosolute zero offset provided - no need to align
     zero_electric_angle = zero_electric_offset;
     // set the sensor direction - default CW
     sensor_direction = _sensor_direction;
   }

   // sensor and motor alignment - can be skipped
   // by setting motor.sensor_direction and motor.zero_electric_angle
   _delay(500);
   if(sensor) exit_flag *= alignSensor();

   // aligning the current sensor - can be skipped
   // checks if driver phases are the same as current sense phases
   // and checks the direction of measuremnt.
   _delay(500);

   if(!exit_flag){
     disable();
   }

   return exit_flag;
 }

 // Encoder alignment to electrical 0 angle
 int BLDCMotor::alignSensor() {
   int exit_flag = 1; //success

   // if unknown natural direction
   if(!_isset(sensor_direction)){
     // check if sensor needs zero search
     if(sensor->needsSearch()) exit_flag = absoluteZeroSearch();
     // stop init if not found index
     if(!exit_flag) return exit_flag;

     // find natural direction
     // move one electrical revolution forward
     for (int i = 0; i <=500; i++ ) {
       float angle = _3PI_2 + _2PI * i / 500.0;
       setPhaseVoltage(voltage_sensor_align, 0,  angle);
       _delay(2);
     }
     // take and angle in the middle
     float mid_angle = sensor->getAngle();
     // move one electrical revolution backwards
     for (int i = 500; i >=0; i-- ) {
       float angle = _3PI_2 + _2PI * i / 500.0 ;
       setPhaseVoltage(voltage_sensor_align, 0,  angle);
       _delay(2);
     }
     float end_angle = sensor->getAngle();
     setPhaseVoltage(0, 0, 0);
     _delay(200);
     // determine the direction the sensor moved
     if (mid_angle == end_angle) {
       return 0; // failed calibration
     } else if (mid_angle < end_angle) {
       sensor_direction = Direction::CCW;
     } else{
       sensor_direction = Direction::CW;
     }
   }

   // zero electric angle not known
   if(!_isset(zero_electric_angle)){
     // align the electrical phases of the motor and sensor
     // set angle -90(270 = 3PI/2) degrees
     setPhaseVoltage(voltage_sensor_align, 0,  _3PI_2);
     _delay(700);
     zero_electric_angle = _normalizeAngle(_electricalAngle(sensor_direction*sensor->getAngle(), pole_pairs));
     _delay(20);
     // stop everything
     setPhaseVoltage(0, 0, 0);
     _delay(200);
   }
   return exit_flag;
 }

 // Encoder alignment the absolute zero angle
 // - to the index
 int BLDCMotor::absoluteZeroSearch() {

   // search the absolute zero with small velocity
   float limit_vel = velocity_limit;
   float limit_volt = voltage_limit;
   velocity_limit = velocity_index_search;
   voltage_limit = voltage_sensor_align;
   shaft_angle = 0;
   while(sensor->needsSearch() && shaft_angle < _2PI){
     angleOpenloop(1.5*_2PI);
     // call important for some sensors not to loose count
     // not needed for the search
     sensor->getAngle();
   }
   // disable motor
   setPhaseVoltage(0, 0, 0);
   // reinit the limits
   velocity_limit = limit_vel;
   voltage_limit = limit_volt;
   // check if the zero found
//   if(monitor_port){
//     if(sensor->needsSearch()) monitor_port->println(F("MOT: Error: Not found!"));
//     else monitor_port->println(F("MOT: Success!"));
//   }
   return !sensor->needsSearch();
 }

 // Iterative function looping FOC algorithm, setting Uq on the Motor
 // The faster it can be run the better
 void BLDCMotor::loopFOC() {
   // if disabled do nothing
   if(!enabled) return;
   // if open-loop do nothing
   if( controller==MotionControlType::angle_openloop || controller==MotionControlType::velocity_openloop ) return;

   // shaft angle
   shaft_angle = shaftAngle();
   // electrical angle - need shaftAngle to be called first
   electrical_angle = electricalAngle();
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

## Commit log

2023-11-23 Cad & Elec
    [BLDCMotor.step, BackPlate.step, Enclosure.step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]
2023-11-23 KICAD's footprint/symbol/cad
    [52207-1260.stp, BMI088.step, CC2520RHDRG4.STEP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]
2024-01-09 add stuff
    [Base.SLDPRT, Base_bare.SLDASM, Glass.step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]
2024-01-09 creating stm32 firmware & setting up IOC

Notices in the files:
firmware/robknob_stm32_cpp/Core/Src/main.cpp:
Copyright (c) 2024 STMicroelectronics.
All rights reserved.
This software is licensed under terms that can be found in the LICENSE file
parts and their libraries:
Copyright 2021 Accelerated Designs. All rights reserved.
